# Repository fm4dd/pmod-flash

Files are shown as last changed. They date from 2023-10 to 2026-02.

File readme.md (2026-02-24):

## Flash PMOD



### Description

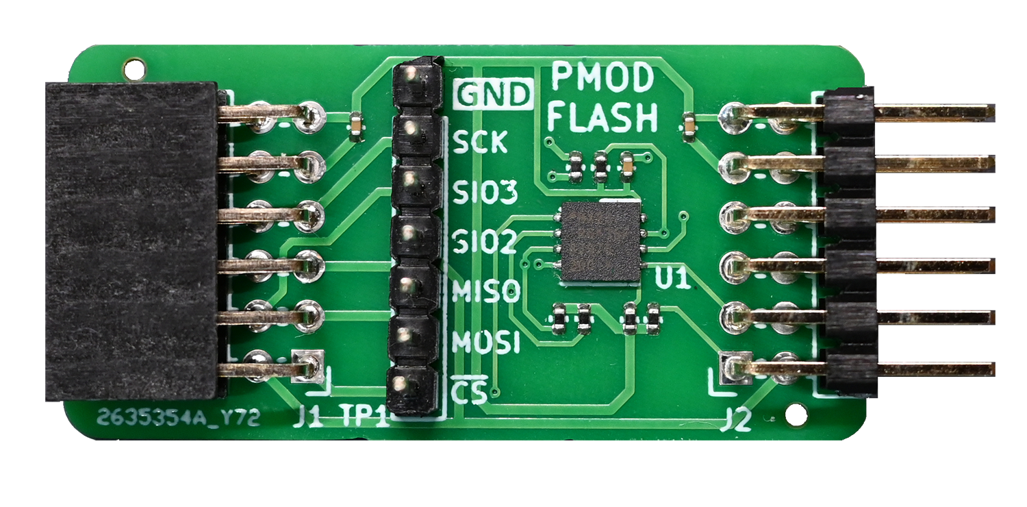
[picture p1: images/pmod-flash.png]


This PMOD provides the Macronix MX25R6435F SPI Flash memory in a pass-through PMOD connector board. The MX25R6435F is a	64Mbit (8MByte) Serial NOR Flash that can operate in multiple modes up to 80Mhz Quad SPI. The PMOD includes the option to install a 7-pin 2.54mm pitch testpoint header for signal and protocol analysis.

https://www.mxic.com.tw/en-us/products/NOR-Flash/Pages/Ultra-Low-Power-Flash.aspx

http://fpga.fm4dd.com/

### Schematic
PMOD Flash Schematics

### PCB Gerber
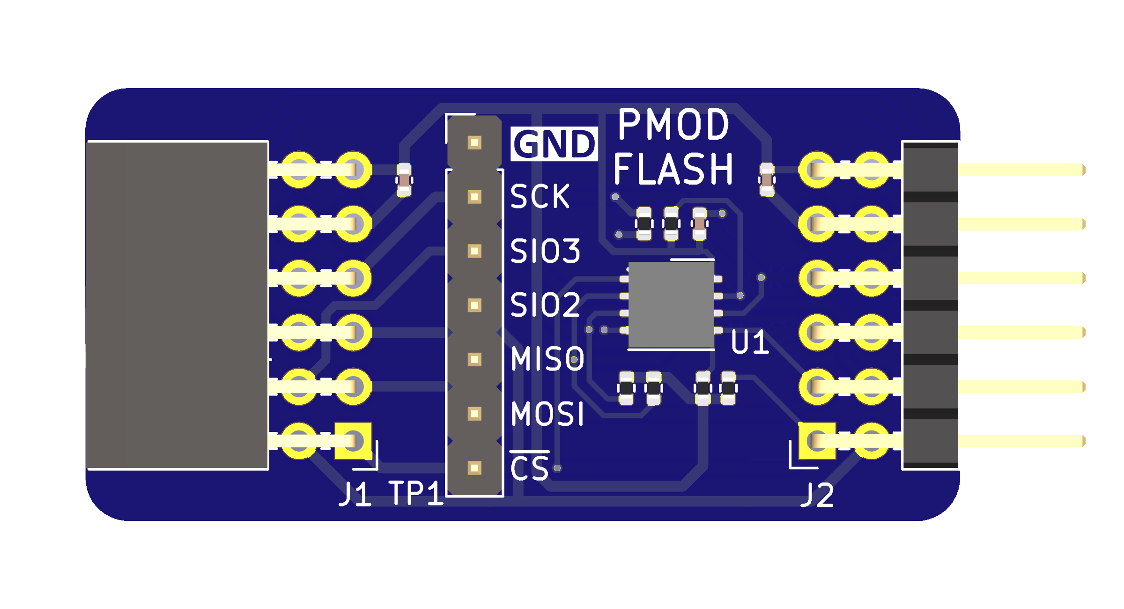
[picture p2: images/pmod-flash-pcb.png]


[PMOD Flash Gerber V1.0](fabfiles/v10/20230921-pmod-flash-gerber.zip)

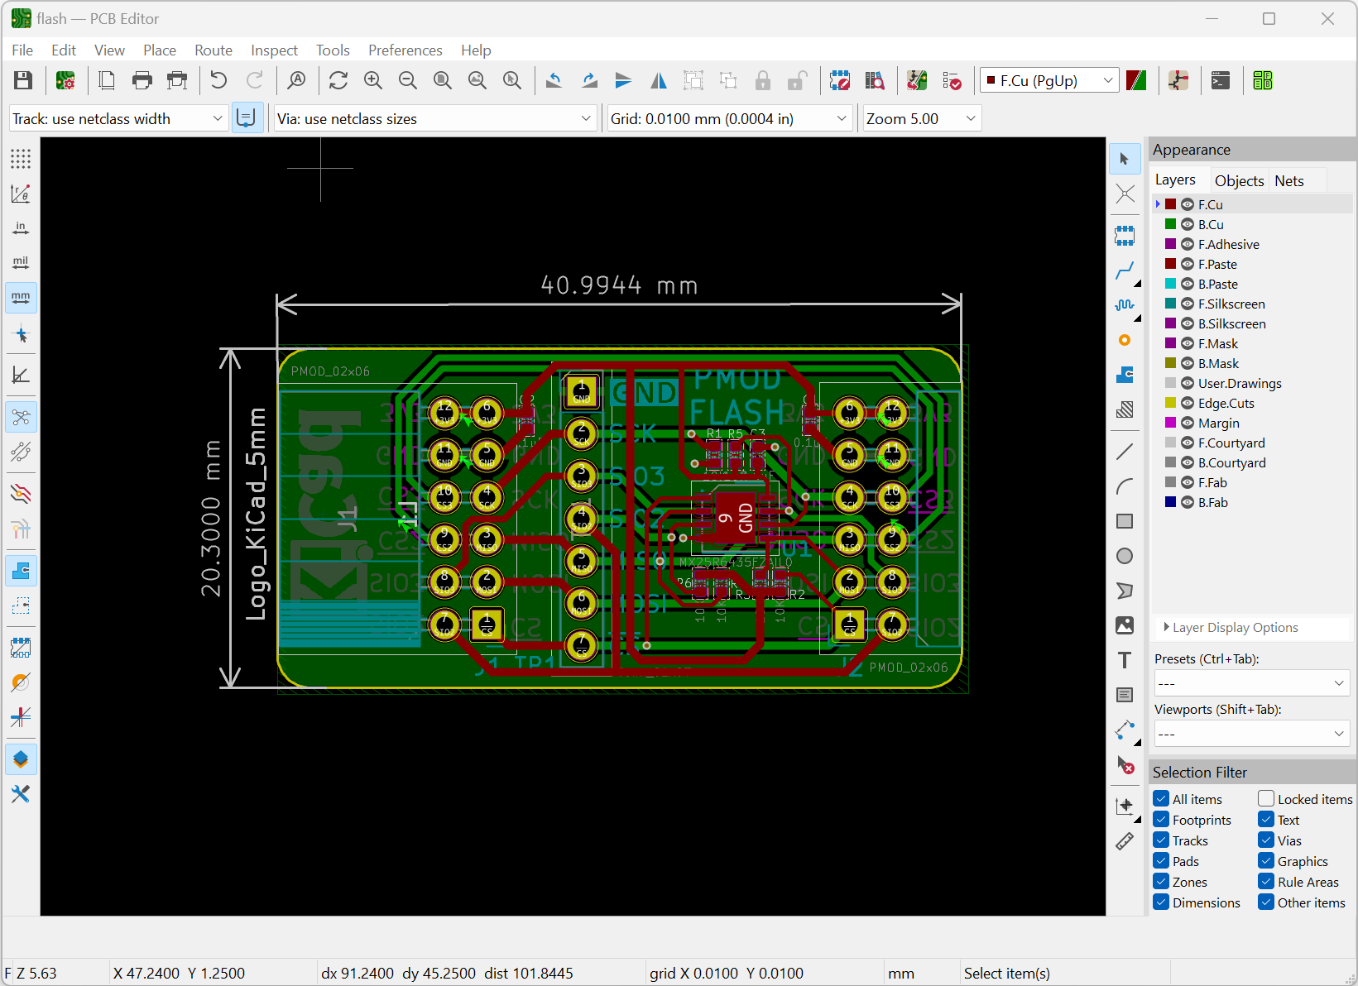
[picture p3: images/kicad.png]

The PMOD Flash module was designed with KiCad 7

### Pin Assignments
<table>
  <tr><th>Pinout</th><th>Pin</th><th>Function</th><th>Pin</th><th>Function</th></tr>
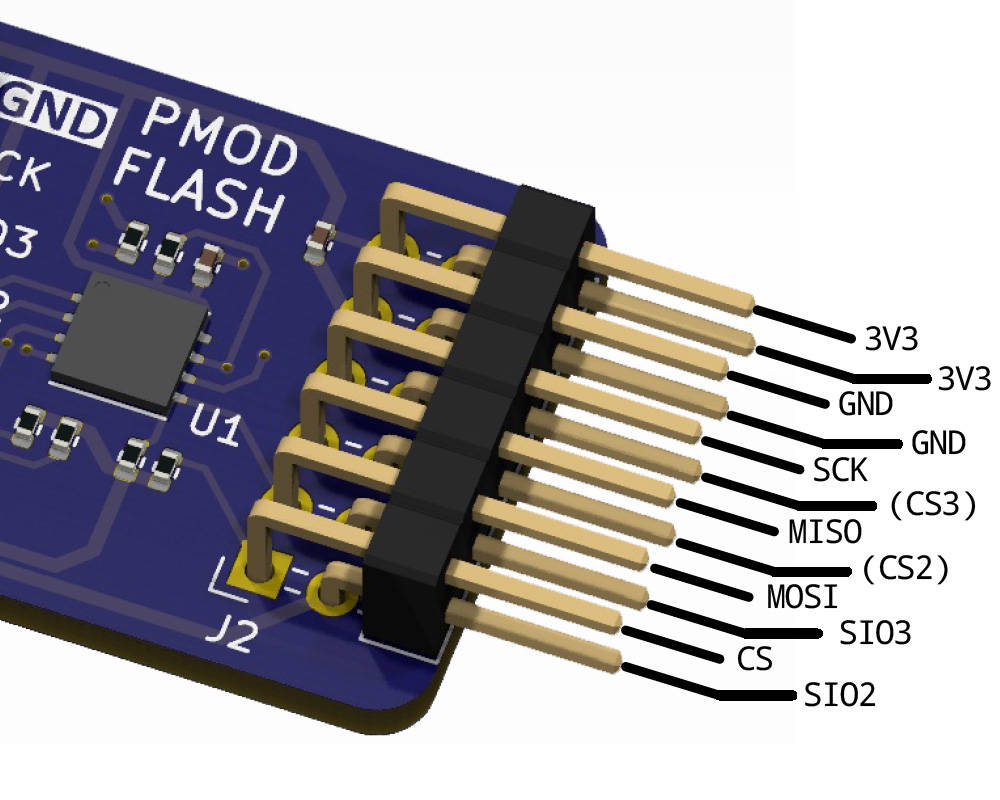
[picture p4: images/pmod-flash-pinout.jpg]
  <tr><td rowspan="6"></td>
        <td>1</td><td>CS</td><td>7</td><td>SIO2</td></tr>
    <tr><td>2</td><td>MOSI</td><td>8</td><td>SIO3</td></tr>
    <tr><td>3</td><td>MISO</td><td>9</td><td> not connected (CS2)</td></tr>
    <tr><td>4</td><td>SCK</td><td>10</td><td>not connected (CS3)</td></tr>
    <tr><td>5</td><td>GND</td><td>11</td><td>GND</td></tr>
    <tr><td>6</td><td>3V3</td><td>12</td><td>3V3</td></tr>
</table>

### Example Code

The following code examples demonstrate the PMOD function for quick verification on various Microcontroller and FPGA platforms.

| Platform | Test Program location | Description |
|---|---|---|
| Arduino |[examples/arduino](examples/arduino) | Flash test adopted from the SparkFun_SPI_SerialFlash library |
| Raspberry  |[examples/rpi](examples/rpi) | Linux has the flashrom program for basic read/write commands |
| Gatemate |[examples/gatemate](examples/gatemate) | Gatemate FPGA test program for basic Flash access validation |
| iCEBreaker |[examples/icebreaker](examples/icebreaker)| iCEBreaker FPGA test program for basic Flash access validation |

### PMOD-Flash Function Tests

PMOD Flash module connected to the PMOD2RPi board, driven by Seeeduino XIAO SAMD21 MCU:

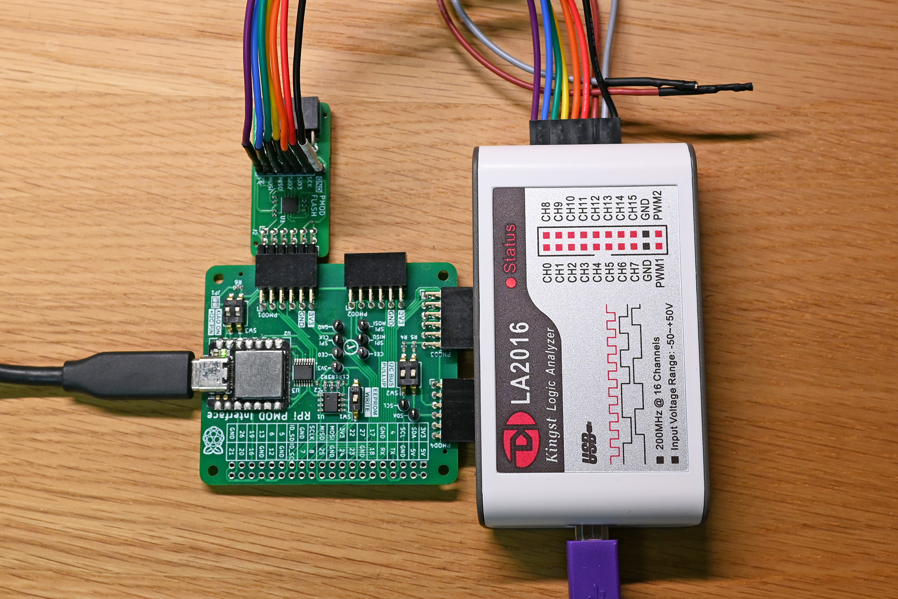
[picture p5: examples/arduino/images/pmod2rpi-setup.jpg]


PMOD Flash module connected to the PMOD2RPi board, interfacing with the Raspberry Pi 4:

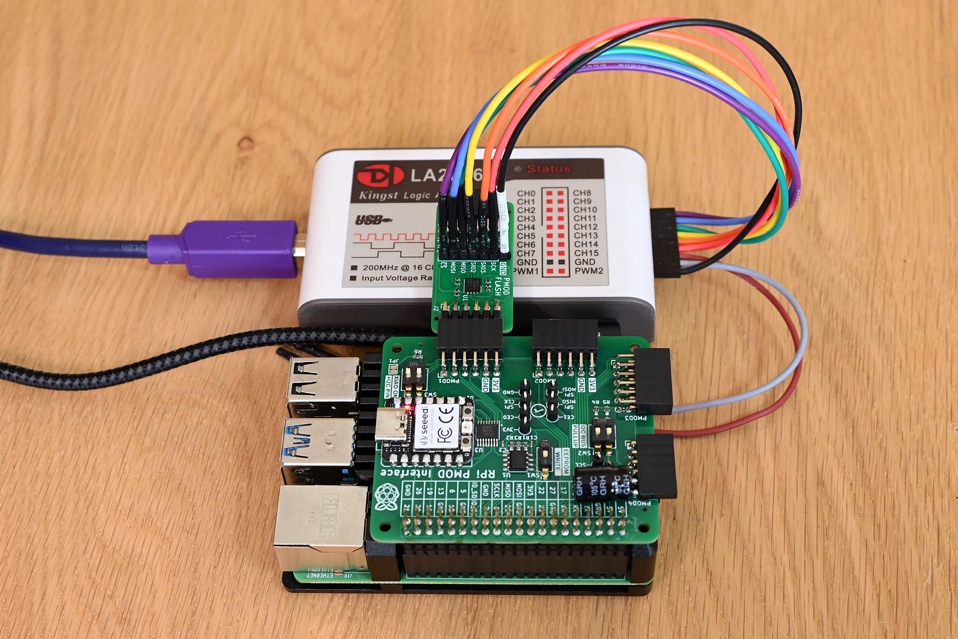
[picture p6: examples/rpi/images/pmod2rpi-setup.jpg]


PMOD Flash module verified running at 50MHz SPI clock speed with the Raspberry Pi 4:

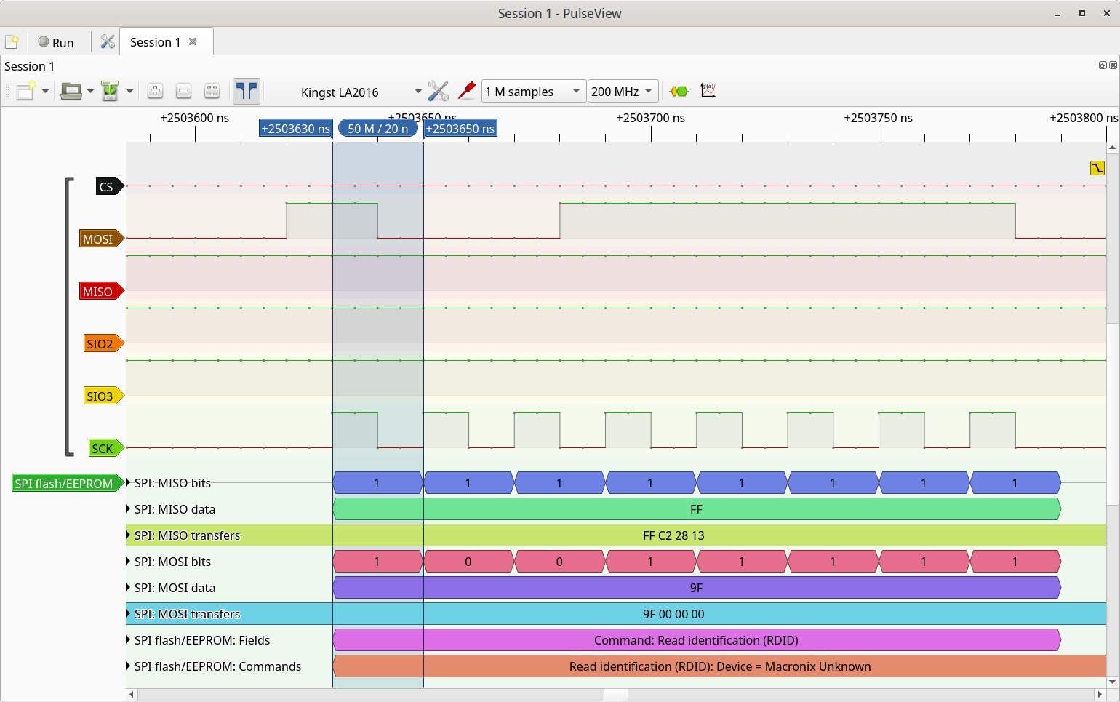
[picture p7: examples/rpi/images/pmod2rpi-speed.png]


PMOD Flash module test on Cologne Chip Gatemate FPGA:

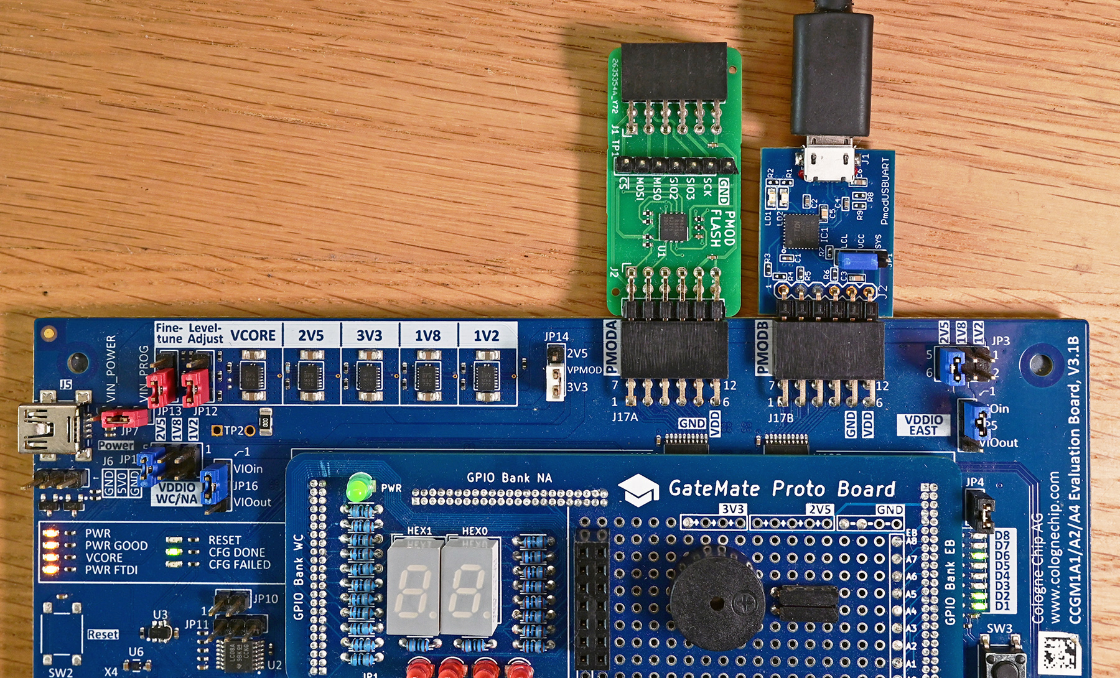
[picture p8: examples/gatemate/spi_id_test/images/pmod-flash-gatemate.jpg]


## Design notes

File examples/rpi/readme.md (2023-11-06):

## Flash PMOD - Raspberry Pi Test Code

### Setup



The PMOD-Flash module has been successfully tested on a Raspberry Pi 4 running Raspberry OS version 11. There, the PMOD-FLash module was connected through the [pmod2rpi board](https://github.com/fm4dd/pmod2rpi). The pmod2rpi board is interfacing with the Raspberry Pi's SPI bus that is exposed on the GPIO pinheader per below connection schematic:

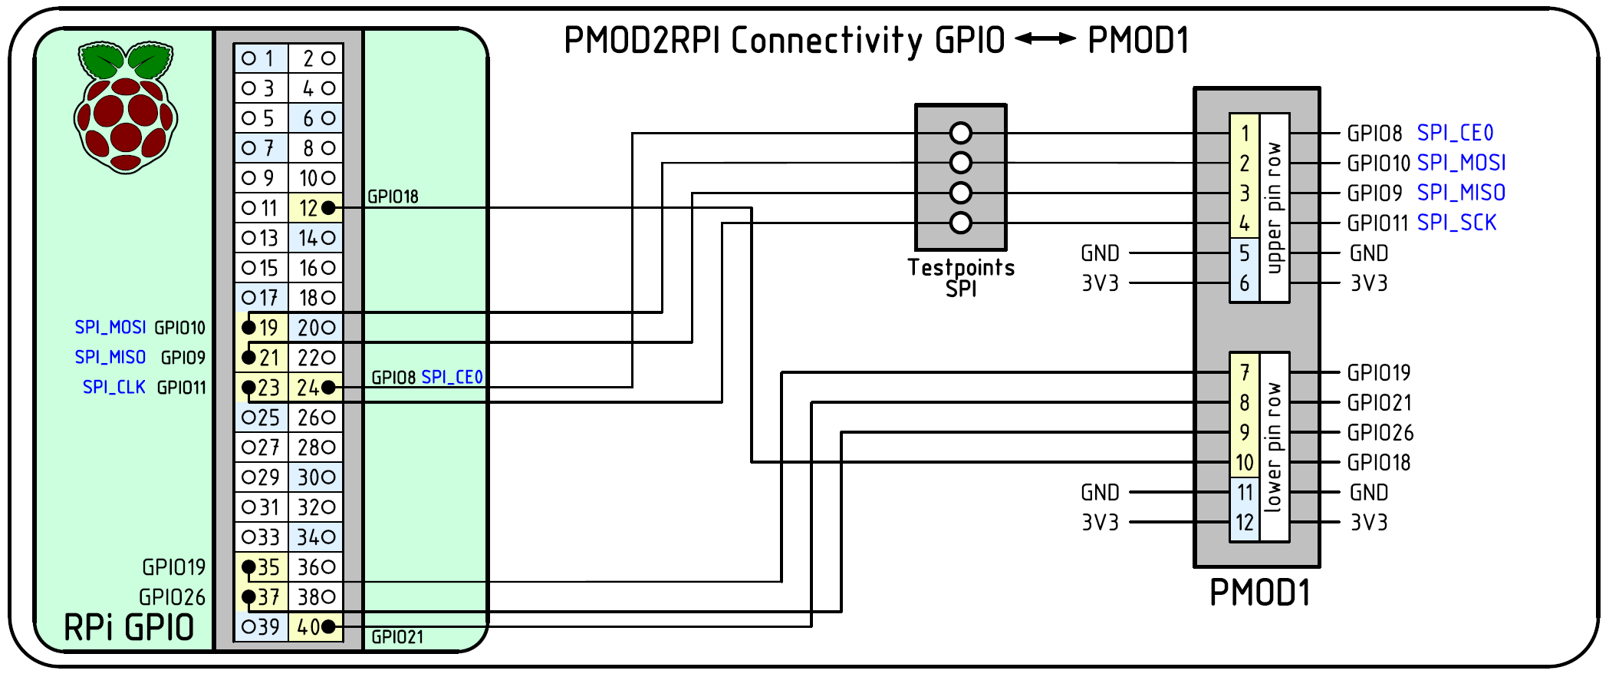
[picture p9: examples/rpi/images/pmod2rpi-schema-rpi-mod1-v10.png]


### Function Test

The Raspberry Pi OS comes with the *flashrom* program that can be used to read or write to the flash module. Below, the *flashrom* program identifies the flash chip vendor and model.

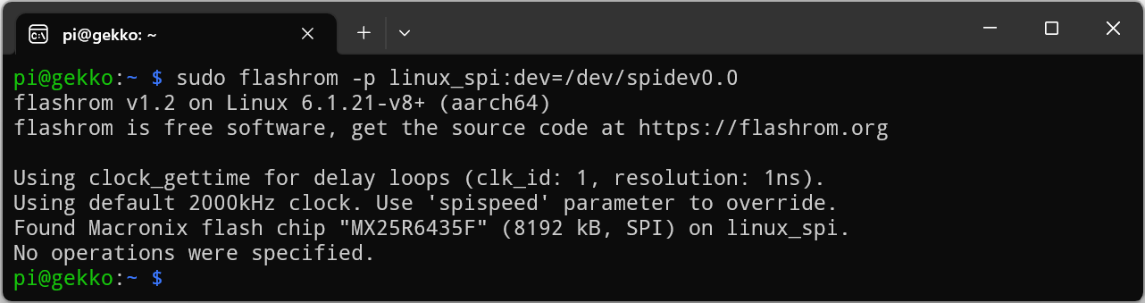
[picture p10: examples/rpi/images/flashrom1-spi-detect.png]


We can dump the entire content from the flash into a local file *rom.img*. The completion time strongly relates to the SPI bus speed setting (given in KHz). In the example below we set 22 MHz for the SPI bus.

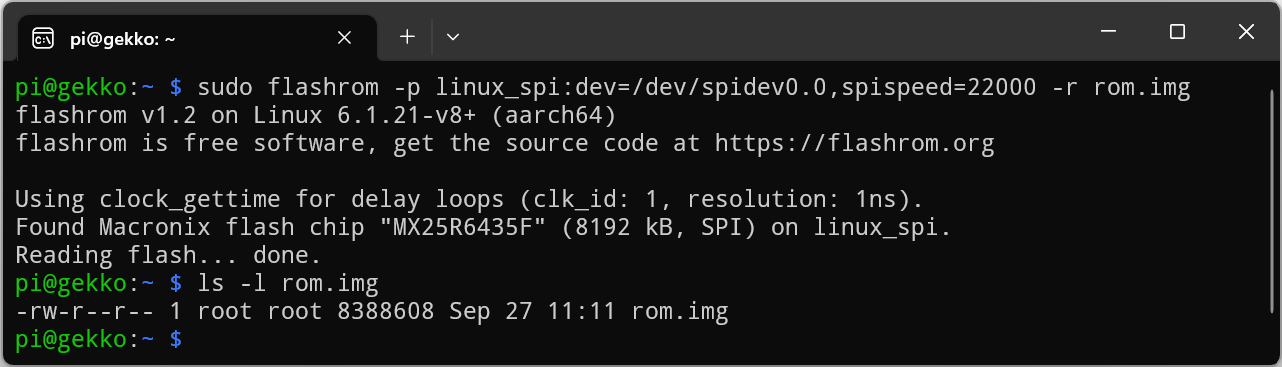
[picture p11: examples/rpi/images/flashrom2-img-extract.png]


After the flash read completes, we can view the flash content from file.

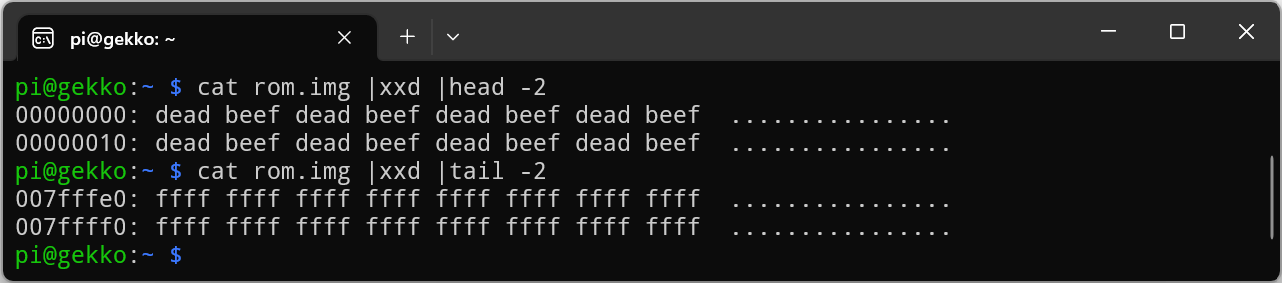
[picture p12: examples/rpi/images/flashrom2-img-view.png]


### SPI Bus Monitoring

 A protocol analyzer was connected directly to the PMOD-Flash analzyer pins to check on SPI clock and protocol information. If a [PMOD-Analyzer board](https://github.com/fm4dd/pmod-analyzer) gets used in between PMOD-flash and pmod2rpi board, the onboard analyzer LEDs must be turned off to let the 10K SPI bus pull-up resistors pull.

Below shows the flash *read identification* command RDID, executed with 50MHz (20 nanoseconds clock period). This is reaching the limit for the attached protocol analyzer, which has a maximum sample rate of 200 MHz. The waveform dots representing the samples show we are down to only two samples for each logic level of the SPI clock *SCK*.



On a Raspberry Pi, the SPI clock is reported to run up to 125MHz max (when running at full core clock speed of 250 MHz).

### Flashrom commands reference

#### Write image to flash

Create a dummy 8M ROM image to write to the flash:
```
pi@gekko:~ $ dd if=/dev/urandom of=flash_8M.img bs=8388608 count=1 conv=notrunc,fsync
1+0 records in
1+0 records out
8388608 bytes (8.4 MB, 8.0 MiB) copied, 0.349986 s, 24.0 MB/s
```

Instead of ```if=/dev/urandom``` we could use ```if=/dev/zero``` to create a image with 0x00.

Write the random data image to flash:

```
pi@gekko:~ $ sudo flashrom -p linux_spi:dev=/dev/spidev0.0,spispeed=22000 -w flash_8M.img
flashrom v1.2 on Linux 6.1.21-v8+ (aarch64)
flashrom is free software, get the source code at https://flashrom.org

Using clock_gettime for delay loops (clk_id: 1, resolution: 1ns).
Found Macronix flash chip "MX25R6435F" (8192 kB, SPI) on linux_spi.
Reading old flash chip contents... done.
Erasing and writing flash chip... Erase/write done.
Verifying flash... VERIFIED.
```

## Erase the flash

When the flash is erased, it flips every bit to 1 (0xFF content):

```
pi@gekko:~ $ sudo flashrom -p linux_spi:dev=/dev/spidev0.0,spispeed=22000 -E
flashrom v1.2 on Linux 6.1.21-v8+ (aarch64)
flashrom is free software, get the source code at https://flashrom.org

Using clock_gettime for delay loops (clk_id: 1, resolution: 1ns).
Found Macronix flash chip "MX25R6435F" (8192 kB, SPI) on linux_spi.
Erasing and writing flash chip... Erase/write done.
```

## Operations on specific Flash Memory Locations

In order to read or write only partial data to flash, we can select the flash region. The *flashrom* program can read the specific memory location from a layout file. The layout file contains lines for "startaddr:endaddr imagename". The *flashrom* manual has more information.

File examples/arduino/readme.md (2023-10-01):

## Flash PMOD - Arduino Test Code

### Setup



The PMOD-Flash module has been successfully tested on a Arduino-class Seeeduino XIAO board. The XIAO uses a Cortex-M0+ SAMD21G18 microcontroller. The original Sparkfun example code has been adopted from the SparkFun_SPI_SerialFlash library with minor changes to enable serial communication and to externalize the SPI clock speed parameter. All credits for the example code go to Sparkfun.

The XIAO is embedded on the [pmod2rpi board](https://github.com/fm4dd/pmod2rpi), and PMOD-Flash was connected to the PMOD1 connector. On the pmod2rpi board, SW3 was in "on" position. This switch toggles the PMOD1 type between I2C and SPI modes, according to Digilents PMOD specification. I used the SPI_Flash_Example.ino sketch example from the Sparkfun library "SparkFun_SPI_SerialFlash". When connecting to the boards PMOD1 connector, the CS signal is connected to XIAO pin-7. For the PMOD2 connector, its XIAO pin-6.

The original sketch misses the serial wait required for the USB connected serial ports. We can add ```while (!Serial) { ; // wait for serial port to connect. Needed for native USB port only}``` right after ```Serial.begin(115200);```

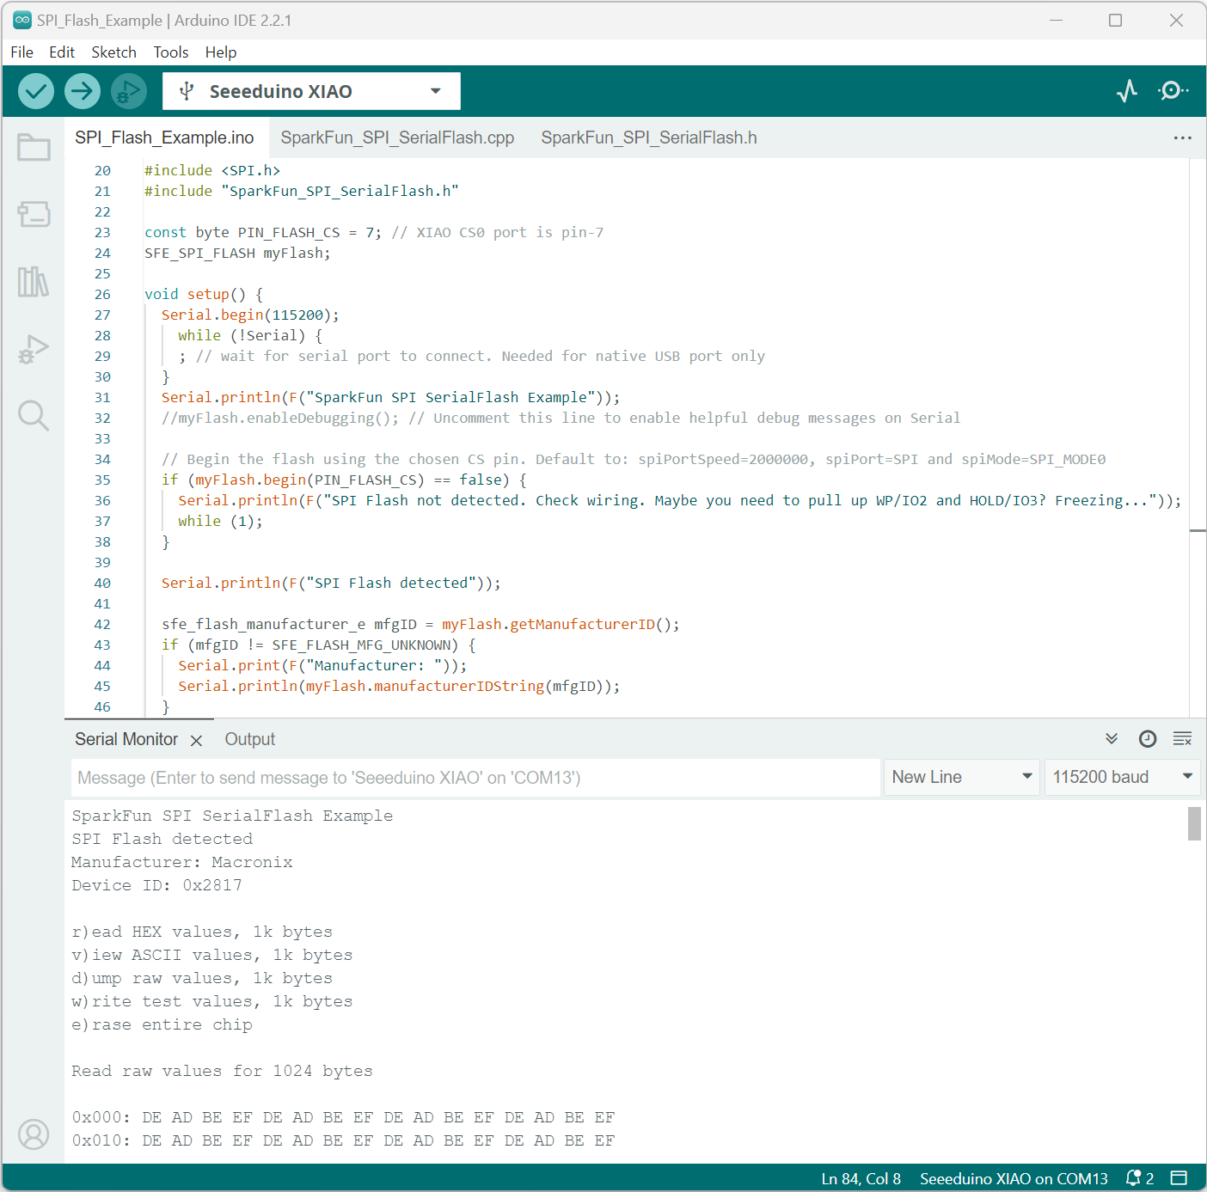
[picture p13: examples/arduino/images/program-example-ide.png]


The example program [SPI_Flash_Example](SPI_Flash_Example/) identifies the flash chip vendor and model, can read from the flash, and write the test byte pattern "de ad be ef" into the first 1K memory of the flash.

### SPI Bus Monitoring

 A protocol analyzer was connected directly to the PMOD-Flash analzyer pins to check on SPI clock and protocol information. If a [PMOD-Analyzer board](https://github.com/fm4dd/pmod-analyzer) gets used in between PMOD-flash and pmod2rpi board, the onboard analyzer LEDs must be turned off to let the 10K SPI bus pull-up resistors pull.

Below shows the flash data write to address 0x0, writing the test pattern "de ad be ef".
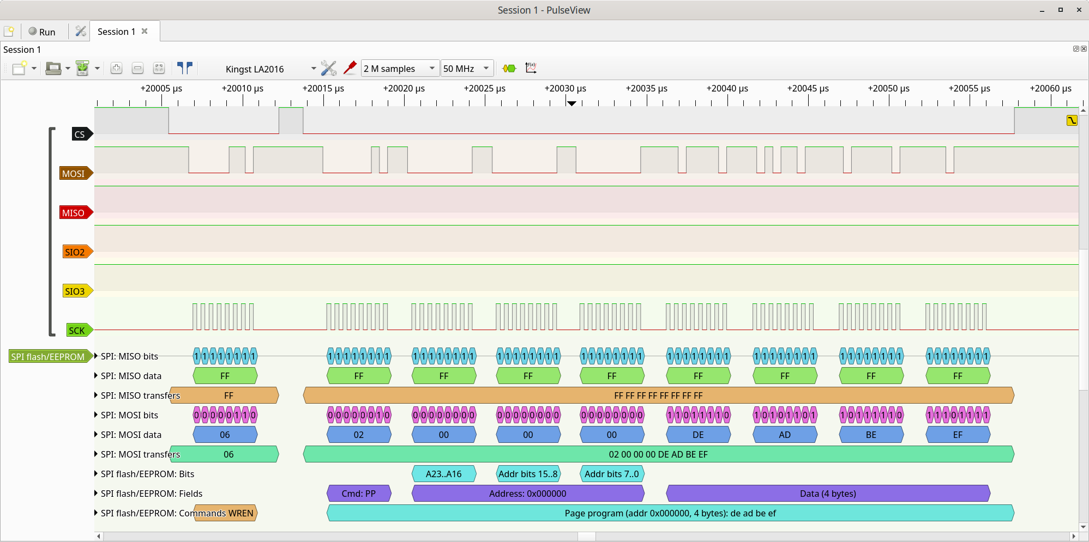
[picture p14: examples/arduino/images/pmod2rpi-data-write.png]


Below shows the flash data read command for address 0x00.
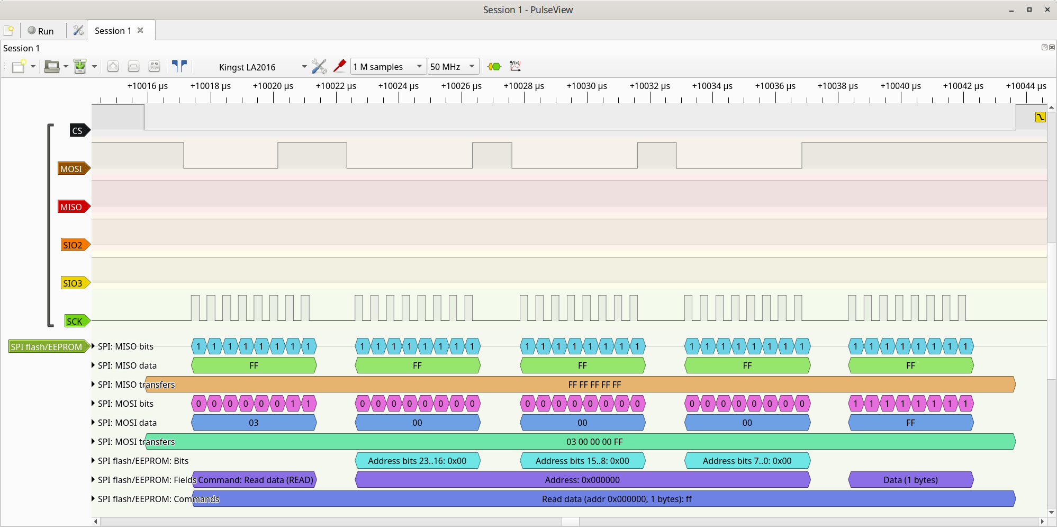
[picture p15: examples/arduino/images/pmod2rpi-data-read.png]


Note the programs default SPI speed is 2 MHz. The max possible SPI master speed of the Cortex-M0 microcontroller SAMD21G18 is 12 MHz. (https://microchip.my.site.com/s/article/SPI-max-clock-frequency-in-SAMD-SAMR-devices)

### Example Program Serial Output
```
SparkFun SPI SerialFlash Example
SPI Flash detected
Manufacturer: Macronix
Device ID: 0x2817

r)ead HEX values, 1k bytes
v)iew ASCII values, 1k bytes
d)ump raw values, 1k bytes
w)rite test values, 1k bytes
e)rase entire chip
```
Typing 'e':
```
Read raw values for 1024 bytes

0x000: FF FF FF FF FF FF FF FF FF FF FF FF FF FF FF FF
0x010: FF FF FF FF FF FF FF FF FF FF FF FF FF FF FF FF
0x020: FF FF FF FF FF FF FF FF FF FF FF FF FF FF FF FF
0x030: FF FF FF FF FF FF FF FF FF FF FF FF FF FF FF FF
0x040: FF FF FF FF FF FF FF FF FF FF FF FF FF FF FF FF
0x050: FF FF FF FF FF FF FF FF FF FF FF FF FF FF FF FF
0x060: FF FF FF FF FF FF FF FF FF FF FF FF FF FF FF FF
...
0x3C0: FF FF FF FF FF FF FF FF FF FF FF FF FF FF FF FF
0x3D0: FF FF FF FF FF FF FF FF FF FF FF FF FF FF FF FF
0x3E0: FF FF FF FF FF FF FF FF FF FF FF FF FF FF FF FF
0x3F0: FF FF FF FF FF FF FF FF FF FF FF FF FF FF FF FF

r)ead HEX values, 1k bytes
v)iew ASCII values, 1k bytes
d)ump raw values, 1k bytes
w)rite test values, 1k bytes
e)rase entire chip
```
Typing 'v':
```
(returns empty lines, 0xFF does not translate into an ASCII character)

r)ead HEX values, 1k bytes
v)iew ASCII values, 1k bytes
d)ump raw values, 1k bytes
w)rite test values, 1k bytes
e)rase entire chip
```
Typing 'd':
 ```        ...
r)ead HEX values, 1k bytes
v)iew ASCII values, 1k bytes
d)ump raw values, 1k bytes
w)rite test values, 1k bytes
e)rase entire chip
```
Typing 'w':
```
Writing test HEX values to first 1024 bytes

r)ead HEX values, 1k bytes
v)iew ASCII values, 1k bytes
d)ump raw values, 1k bytes
w)rite test values, 1k bytes
e)rase entire chip

Typing 'r':

Read raw values for 1024 bytes

0x000: DE AD BE EF DE AD BE EF DE AD BE EF DE AD BE EF
0x010: DE AD BE EF DE AD BE EF DE AD BE EF DE AD BE EF
0x020: DE AD BE EF DE AD BE EF DE AD BE EF DE AD BE EF
0x030: DE AD BE EF DE AD BE EF DE AD BE EF DE AD BE EF
...
0x3C0: DE AD BE EF DE AD BE EF DE AD BE EF DE AD BE EF
0x3D0: DE AD BE EF DE AD BE EF DE AD BE EF DE AD BE EF
0x3E0: DE AD BE EF DE AD BE EF DE AD BE EF DE AD BE EF
0x3F0: DE AD BE EF DE AD BE EF DE AD BE EF DE AD BE EF

r)ead HEX values, 1k bytes
v)iew ASCII values, 1k bytes
d)ump raw values, 1k bytes
w)rite test values, 1k bytes
e)rase entire chip
```
Typing 'e':
```
Erasing entire chip

r)ead HEX values, 1k bytes
v)iew ASCII values, 1k bytes
d)ump raw values, 1k bytes
w)rite test values, 1k bytes
e)rase entire chip
```
Typing 'r':
```
Read raw values for 1024 bytes

0x000: FF FF FF FF FF FF FF FF FF FF FF FF FF FF FF FF
0x010: FF FF FF FF FF FF FF FF FF FF FF FF FF FF FF FF
0x020: FF FF FF FF FF FF FF FF FF FF FF FF FF FF FF FF
0x030: FF FF FF FF FF FF FF FF FF FF FF FF FF FF FF FF
...
0x3C0: FF FF FF FF FF FF FF FF FF FF FF FF FF FF FF FF
0x3D0: FF FF FF FF FF FF FF FF FF FF FF FF FF FF FF FF
0x3E0: FF FF FF FF FF FF FF FF FF FF FF FF FF FF FF FF
0x3F0: FF FF FF FF FF FF FF FF FF FF FF FF FF FF FF FF
```

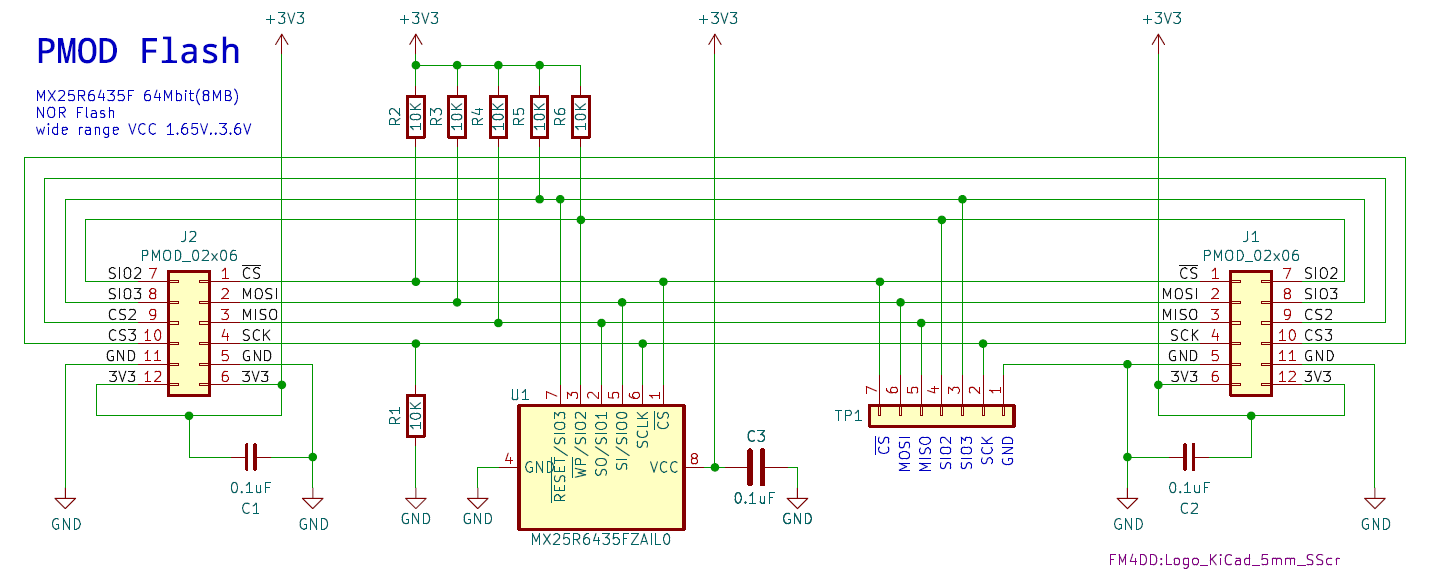
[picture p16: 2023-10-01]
images/schema.png

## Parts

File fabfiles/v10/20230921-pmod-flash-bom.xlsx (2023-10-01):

Comment | Designator | Footprint | JLCPCB Part #（optional）
10K | R1,R2,R3,R4,R5,R6 | R_0402_1005Metric | C25744
0.1uF | C2,C1,C3 | C_0402_1005Metric | C1525
MX25R6435FZAIL0 | U1 | USON-8_4x4mm | C2802847

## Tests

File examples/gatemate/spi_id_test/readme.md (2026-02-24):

## PMOD-FLASH test program

### Description

This is a Verilog test program for the flash chip on PMOD Flash.
It only sends one command 9Fh (Read Identification - RDID), and returns the output to a serial console.

For my test, I connected PMOD Flash to PMODA on the Gatemate E1 FPGA board.
On PMOD2 I have the Digilent pmod USBUART connected to the lower pinrow.

The SPI clock is a simple 4:1 divider, creating a SPI flash clock frequency of 2.5 MHz (10Mhz/4).

Gatemate constraints:
```
## #######################################################
## PMOD-A constraints for github.com/fm4dd/pmod-flash 
## MX25R6435F is a 64Mbit (8MByte) Serial NOR Flash 
## #######################################################
Pin_out "SPIFLASH_CLK"   Loc = "IO_NB_A3";
Pin_out "SPIFLASH_CS_N"  Loc = "IO_NB_A0";
Pin_out "SPIFLASH_MOSI"  Loc = "IO_NB_A1"; # DQ0/MOSI
Pin_in  "SPIFLASH_MISO"  Loc = "IO_NB_A2"; # DQ1/MISO
## #######################################################
## PMOD-B connector constraints for Digilent PMOD USBUART.
## This single-row PMOD is connected to lower (Bx) pin row
## #######################################################
## Lower Row connection  assignment
Pin_out "CTS" Loc = "IO_NB_B4"; # RTS
Pin_out "TXD" Loc = "IO_NB_B5"; # RXD
Pin_in  "RXD" Loc = "IO_NB_B6"; # TXD
Pin_out "RTS" Loc = "IO_NB_B7"; # CTS
```

PMOD Flash module test on Cologne Chip Gatemate FPGA:



### Build FPGA Bitstream

```
$ make
/home/fm/oss-cad-suite/bin/yosys -ql log/synth.log -p 'read -sv src/spi_id_test.v src/emmitter_uart.v; synth_gatemate -top spi_id_test -luttree -nomx8 -vlog net/spi_id_test_synth.v; write_json net/spi_id_test_synth.json'
test -e src/gatemate-e1.ccf || exit
/home/fm/oss-cad-suite/bin/nextpnr-himbaechel --device=CCGM1A1 --json net/spi_id_test_synth.json --write net/spi_id_test_impl.v -o out=net/spi_id_test_impl.txt -o ccf=src/gatemate-e1.ccf --router router2 > log/impl.log
Info: Using uarch 'gatemate' for device 'CCGM1A1'
Info: Using timing mode 'WORST'
Info: Using operation mode 'SPEED'
...
Info: Device utilisation:
Info: 	            USR_RSTN:       0/      1     0%
Info: 	            CPE_COMP:       0/  20480     0%
Info: 	         CPE_CPLINES:      10/  20480     0%
Info: 	               IOSEL:      15/    162     9%
Info: 	                GPIO:      15/    162     9%
Info: 	               CLKIN:       1/      1   100%
Info: 	              GLBOUT:       1/      1   100%
Info: 	                 PLL:       0/      4     0%
Info: 	            CFG_CTRL:       0/      1     0%
Info: 	              SERDES:       0/      1     0%
Info: 	              CPE_LT:     364/  40960     0%
Info: 	              CPE_FF:     100/  40960     0%
Info: 	           CPE_RAMIO:      10/  40960     0%
Info: 	            RAM_HALF:       0/     64     0%
...
Info: Program finished normally.
/home/fm/oss-cad-suite/bin/gmpack --input net/spi_id_test_impl.txt --bit spi_id_test.bit
```

### Board Programming
```
$ make prog
Programming E1 SPI Config:
/home/fm/oss-cad-suite/bin/openFPGALoader  -b gatemate_evb_spi spi_id_test.bit
empty
Jtag frequency : requested 6.00MHz    -> real 6.00MHz   
JEDEC ID: 0xc22817
Detected: Macronix MX25R6435F 128 sectors size: 64Mb
00000000 00000000 00000000 00
start addr: 00000000, end_addr: 00010000
Erasing: [==================================================] 100.00%
Done
Writing: [==================================================] 100.00%
Done
Wait for CFG_DONE DONE
```
### Output
With the UART assigned to the E1 boards PMODB connector pins, we can display the serial data in a terminal window.

```
$ ./terminal.sh 
picocom v3.1

port is        : /dev/ttyUSB2
flowcontrol    : none
baudrate is    : 1000000
parity is      : none
databits are   : 8
stopbits are   : 1
escape is      : C-a
local echo is  : no
noinit is      : no
noreset is     : no
hangup is      : no
nolock is      : no
send_cmd is    : sz -vv
receive_cmd is : rz -vv -E
imap is        : 
omap is        : 
emap is        : crcrlf,delbs,
logfile is     : none
initstring     : none
exit_after is  : not set
exit is        : no

Type [C-a] [C-h] to see available commands
Terminal ready
Chip ID: C2 28 17 
Chip ID: C2 28 17 
Chip ID: C2 28 17 

Terminating...
Thanks for using picocom
```
Exit picocom with CTL-A followed by CTL-X.

Notice the device identification ID is "C2 28 17" = Macronix MX25R6435F.

* Manufacturer C2 = Macronix
* memory type: 28 = 3V (3.3V) Serial NOR Flash
* mem density: 17 = 64Mbit (8 Megabytes)

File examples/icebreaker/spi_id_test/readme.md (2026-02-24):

## PMOD-FLASH test program

### Description

This is a Verilog test program for the flash chip on PMOD Flash.
It only sends one command 9Fh (Read Identification - RDID), and returns the output to a serial console.

For my test, I connected PMOD Flash to PMOD1B on the iCEBreaker FPGA board.
On PMOD2 I connected the Digilent pmod 8LD to get the 8-LED diagnostics output.

iCEBreaker constraints:
```
## ##################################################
## iCEBreaker board constraints
## ##################################################
set_io -nowarn CLK        35 # 12 MHz clock
set_io -nowarn RXD         6
set_io -nowarn TXD         9
set_io -nowarn RESET      10

## ##################################################
## PMOD1B constraints for github.com/fm4dd/pmod-flash
# MX25R6435F is a 64Mbit (8MByte) Serial NOR Flash
## ##################################################
set_io -nowarn SPIFLASH_CS_N 43
set_io -nowarn SPIFLASH_MOSI 38
set_io -nowarn SPIFLASH_MISO 34
set_io -nowarn SPIFLASH_CLK  31

## ##################################################
## PMOD2 connector constraints for Digilent PMOD 8LD
## ##################################################
set_io -nowarn LEDS[7]     27
set_io -nowarn LEDS[6]     25
set_io -nowarn LEDS[5]     21
set_io -nowarn LEDS[4]     19
set_io -nowarn LEDS[3]     26
set_io -nowarn LEDS[2]     23
set_io -nowarn LEDS[1]     20
set_io -nowarn LEDS[0]     18
```

PMOD Flash module test on iCEBreaker FPGA:

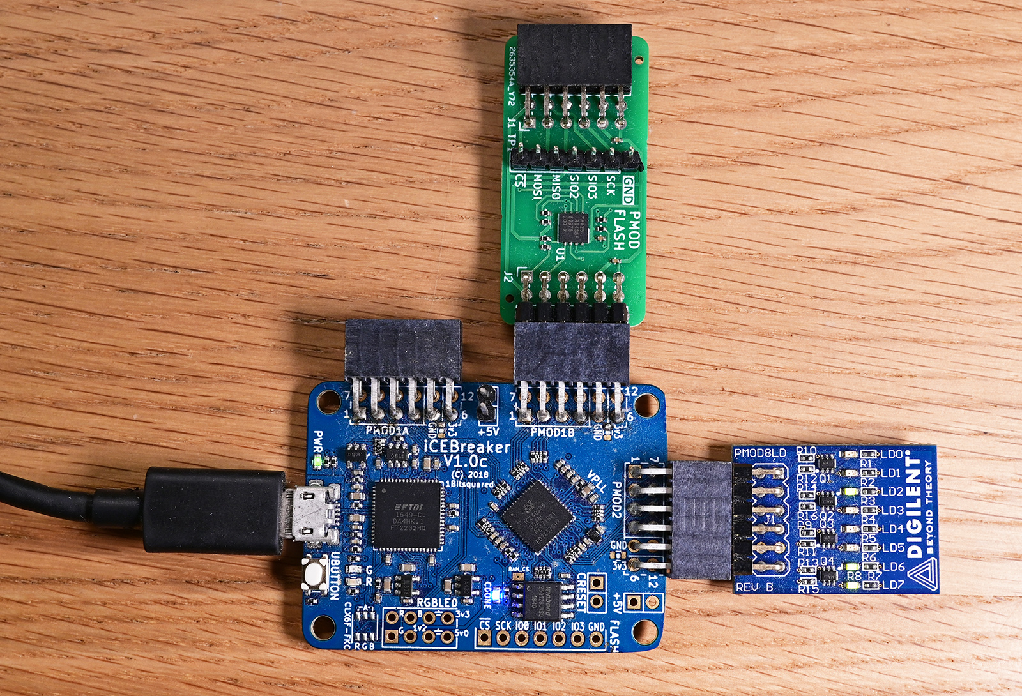
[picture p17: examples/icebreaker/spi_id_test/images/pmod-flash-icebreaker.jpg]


### Build FPGA Bitstream

```
$ make clean; make
rm -f spi_id_test.json spi_id_test.asc spi_id_test.rpt spi_id_test.bin spi_id_test.vcd spi_id_test.tb abc.history spi_id_test.tb
/home/fm/oss-cad-suite/bin/yosys -p 'synth_ice40 -top spi_id_test -json spi_id_test.json' src/spi_id_test.v src/emitter_uart.v

 /----------------------------------------------------------------------------\
 |  yosys -- Yosys Open SYnthesis Suite                                       |
 |  Copyright (C) 2012 - 2026  Claire Xenia Wolf <claire@yosyshq.com>         |
 |  Distributed under an ISC-like license, type "license" to see terms        |
 \----------------------------------------------------------------------------/
 Yosys 0.62+55 (git sha1 29a270c4b, clang++ 18.1.8 -fPIC -O3)
...
=== spi_id_test ===

        +----------Local Count, excluding submodules.
        | 
      231 wires
      438 wire bits
      231 public wires
      438 public wire bits
        8 ports
       15 port bits
        1 cells
        1   $scopeinfo
      328 submodules
       42   SB_CARRY
        1   SB_DFF
       39   SB_DFFE
       21   SB_DFFESR
        8   SB_DFFESS
       26   SB_DFFSR
        5   SB_DFFSS
      186   SB_LUT4
...
Info: Program finished normally.
/home/fm/oss-cad-suite/bin/icetime -d up5k -mtr spi_id_test.rpt spi_id_test.asc
// Reading input .asc file..
// Reading 5k chipdb file..
// Creating timing netlist..
// Timing estimate: 20.52 ns (48.73 MHz)
/home/fm/oss-cad-suite/bin/icepack spi_id_test.asc spi_id_test.bin
```

### Board Programming
```
$ make prog
Programming to Flash:
/home/fm/oss-cad-suite/bin/iceprog spi_id_test.bin
init..
cdone: high
reset..
cdone: low
flash ID: 0xEF 0x40 0x18 0x00
file size: 104090
erase 64kB sector at 0x000000..
erase 64kB sector at 0x010000..
programming..
done.                 
reading..
VERIFY OK             
cdone: high
Bye.
```
### Output
On iCEBreaker we get to onboard UART typically as device /dev/ttyUSB1, we can display the serial data in a terminal window.

```
$ ./terminal.sh 
picocom v3.1

port is        : /dev/ttyUSB1
flowcontrol    : none
baudrate is    : 1000000
parity is      : none
databits are   : 8
stopbits are   : 1
escape is      : C-a
local echo is  : no
noinit is      : no
noreset is     : no
hangup is      : no
nolock is      : no
send_cmd is    : sz -vv
receive_cmd is : rz -vv -E
imap is        : 
omap is        : 
emap is        : crcrlf,delbs,
logfile is     : none
initstring     : none
exit_after is  : not set
exit is        : no

Type [C-a] [C-h] to see available commands
Terminal ready
Chip ID: C2 28 17 
Chip ID: C2 28 17 
Chip ID: C2 28 17 

Terminating...
Thanks for using picocom
```
Exit picocom with CTL-A followed by CTL-X.

Notice the device identification ID is "C2 28 17" = Macronix MX25R6435F.

* Manufacturer C2 = Macronix
* memory type: 28 = 3V (3.3V) Serial NOR Flash
* mem density: 17 = 64Mbit (8 Megabytes)

If the module constraints are wrong and the SPI communication fails, the typical serial output becomes "FF FF FF".

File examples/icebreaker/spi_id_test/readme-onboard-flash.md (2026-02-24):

## OnBoard Flash test program

### Description

This is a Verilog test program for the flash chip on PMOD Flash.
It only sends one command 9Fh (Read Identification - RDID), and returns the output to a serial console.

This code also works with the onboard Flash of the iCEBreaker board.

However by default, the onboard flash enters a Deep Power Down (DPD) mode after the bistream has been loaded.
When the Flash is in DPD, it ignores all standard commands—including RDID (0x9F).
Since it ignores the command, it never drives the MISO line, leaving it pulled high (reading as FF).

This means we either must wake the flash up from Deep Power Down (option A),
or (B) have the programming tell the board to disable Deep Power Down after loading the bitstream.

Option A is to add the DPD wake-up logic into the Verilog code before sending the RDID command.

For (B), we can tell bitstream generator program `icepack` to disable DPD mode.
This is done with the option `icepack -s`: disable final deep-sleep SPI flash command after bitstream is loaded

By adding `-s` into the Makefile, and we can query the onboard flash without additional coding.
In the Makefile, we can simply switch between onboard flash and pmod-flash by enabling the right constraints file.

iCEBreaker constraints for the onboard FLash:
```
## ##################################################
## iCEBreaker board constraints
## ##################################################
set_io -nowarn CLK        35 # 12 MHz clock
set_io -nowarn RXD         6
set_io -nowarn TXD         9
set_io -nowarn RESET      10

## ##################################################
## iCEbreaker onboard SPI Flash
## ##################################################
set_io -nowarn SPIFLASH_CLK  15
set_io -nowarn SPIFLASH_CS_N 16
set_io -nowarn SPIFLASH_MOSI 14
set_io -nowarn SPIFLASH_MISO 17

## ##################################################
## PMOD2 connector constraints for Digilent PMOD 8LD
## ##################################################
set_io -nowarn LEDS[7]     27
set_io -nowarn LEDS[6]     25
set_io -nowarn LEDS[5]     21
set_io -nowarn LEDS[4]     19
set_io -nowarn LEDS[3]     26
set_io -nowarn LEDS[2]     23
set_io -nowarn LEDS[1]     20
set_io -nowarn LEDS[0]     18
```

PMOD Flash module test on iCEBreaker FPGA:



### Build FPGA Bitstream

```
$ make clean; make
rm -f spi_id_test.json spi_id_test.asc spi_id_test.rpt spi_id_test.bin spi_id_test.vcd spi_id_test.tb abc.history spi_id_test.tb
/home/fm/oss-cad-suite/bin/yosys -p 'synth_ice40 -top spi_id_test -json spi_id_test.json' src/spi_id_test.v src/emitter_uart.v

 /----------------------------------------------------------------------------\
 |  yosys -- Yosys Open SYnthesis Suite                                       |
 |  Copyright (C) 2012 - 2026  Claire Xenia Wolf <claire@yosyshq.com>         |
 |  Distributed under an ISC-like license, type "license" to see terms        |
 \----------------------------------------------------------------------------/
 Yosys 0.62+55 (git sha1 29a270c4b, clang++ 18.1.8 -fPIC -O3)
...
Info: Device utilisation:
Info: 	         ICESTORM_LC:     210/   5280     3%
Info: 	        ICESTORM_RAM:       0/     30     0%
Info: 	               SB_IO:      15/     96    15%
Info: 	               SB_GB:       3/      8    37%
Info: 	        ICESTORM_PLL:       0/      1     0%
Info: 	         SB_WARMBOOT:       0/      1     0%
Info: 	        ICESTORM_DSP:       0/      8     0%
Info: 	      ICESTORM_HFOSC:       0/      1     0%
Info: 	      ICESTORM_LFOSC:       0/      1     0%
Info: 	              SB_I2C:       0/      2     0%
Info: 	              SB_SPI:       0/      2     0%
Info: 	              IO_I3C:       0/      2     0%
Info: 	         SB_LEDDA_IP:       0/      1     0%
Info: 	         SB_RGBA_DRV:       0/      1     0%
Info: 	      ICESTORM_SPRAM:       0/      4     0%
...
Info: Program finished normally.
/home/fm/oss-cad-suite/bin/icetime -d up5k -mtr spi_id_test.rpt spi_id_test.asc
// Reading input .asc file..
// Reading 5k chipdb file..
// Creating timing netlist..
// Timing estimate: 20.52 ns (48.73 MHz)
/home/fm/oss-cad-suite/bin/icepack -s spi_id_test.asc spi_id_test.bin
```

### Board Programming
```
$ make prog
Programming to Flash:
/home/fm/oss-cad-suite/bin/iceprog spi_id_test.bin
init..
cdone: high
reset..
cdone: low
flash ID: 0xEF 0x40 0x18 0x00
file size: 104090
erase 64kB sector at 0x000000..
erase 64kB sector at 0x010000..
programming..
done.                 
reading..
VERIFY OK             
cdone: high
Bye.
```
### Output
On iCEBreaker we get to onboard UART typically as device /dev/ttyUSB1, we can display the serial data in a terminal window.

```
$ ./terminal.sh 
picocom v3.1

port is        : /dev/ttyUSB1
flowcontrol    : none
baudrate is    : 1000000
parity is      : none
databits are   : 8
stopbits are   : 1
escape is      : C-a
local echo is  : no
noinit is      : no
noreset is     : no
hangup is      : no
nolock is      : no
send_cmd is    : sz -vv
receive_cmd is : rz -vv -E
imap is        : 
omap is        : 
emap is        : crcrlf,delbs,
logfile is     : none
initstring     : none
exit_after is  : not set
exit is        : no

Type [C-a] [C-h] to see available commands
Terminal ready
Chip ID: EF 40 18 
Chip ID: EF 40 18 
Chip ID: EF 40 18 

Terminating...
Thanks for using picocom
```
Exit picocom with CTL-A followed by CTL-X.

Notice the device identification ID is "EF 40 18" = Winbond W25Q128.

* Manufacturer EF = Winbond
* memory type: 40 = W25Q series
* mem density: 18 = 128Mbit (16 Megabytes. Capacity 0x18 = 24 decimal, 2^24 bits = 16MB) 

If the module constraints are wrong and the SPI communication fails, the typical serial output becomes "FF FF FF".

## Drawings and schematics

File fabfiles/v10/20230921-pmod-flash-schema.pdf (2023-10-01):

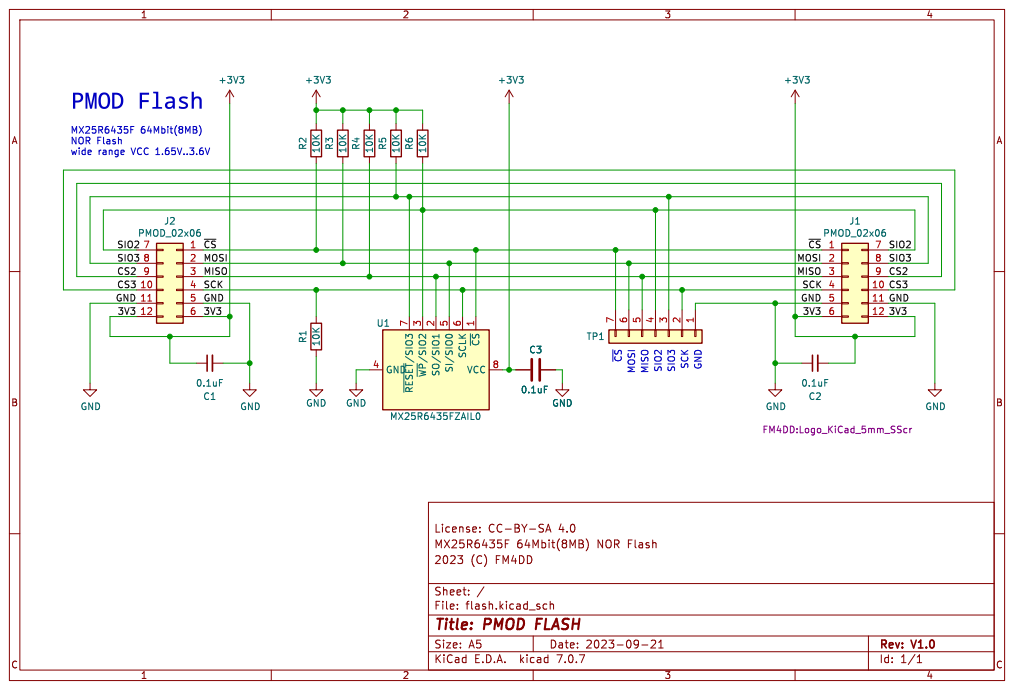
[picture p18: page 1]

Id: 1/1 Title: PMOD FLASH

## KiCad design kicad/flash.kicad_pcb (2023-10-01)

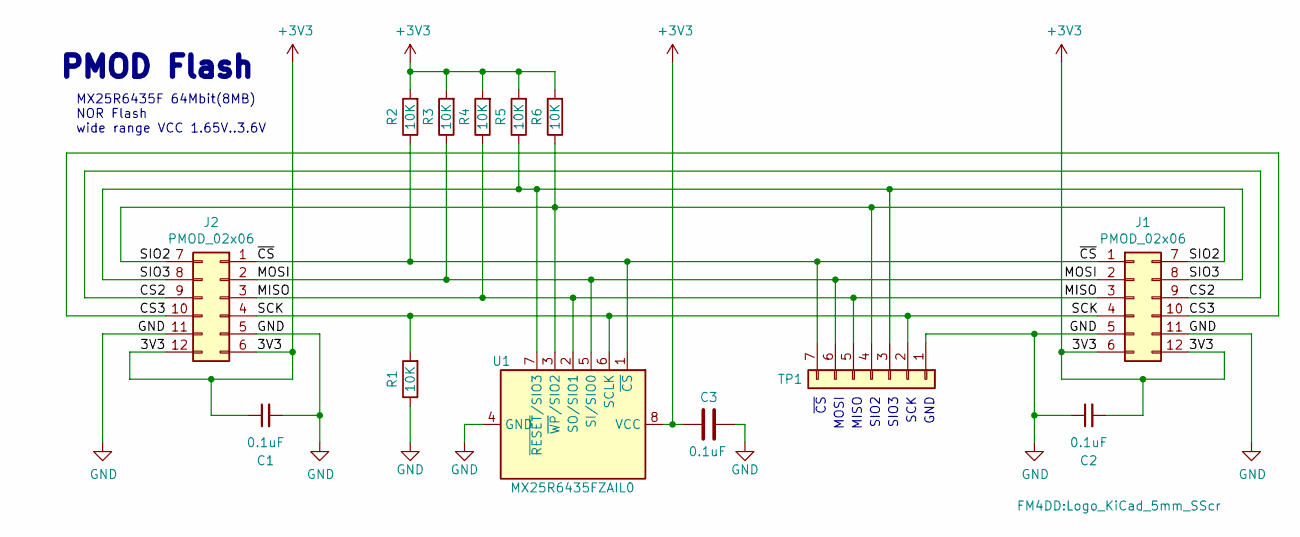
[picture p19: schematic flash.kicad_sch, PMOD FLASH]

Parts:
C1, C2: 0.1uF; C_0402_1005Metric
C3: 0.1uF; C_0402_1005Metric; MPN CC0402KRX7R7BB104; LCSC C327009
J1: PMOD_02x06; PMODPinSocket_2x06_P2.54mm_Horizontal
J2: PMOD_02x06; PMODHeader_2x06_P2.54mm_Horizontal
L1: Logo_KiCad_5mm; Logo_KiCad_5mm_SScr
R1, R2, R3, R4, R5, R6: 10K; R_0402_1005Metric; MPN RC0402JR-075K1L
TP1: Conn_01x07; PinHeader_1x07_P2.54mm_Vertical
U1: MX25R6435FZAIL0; USON-8_4x4mm

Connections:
+3V3: C1.1, C2.2, C3.1, J1.6, J1.12, J2.6, J2.12, R2.2, R3.2, R4.2, R5.2, R6.2, U1.8 (VCC)
/CS2: J1.9, J2.9
/CS3: J1.10, J2.10
/MISO: J1.3, J2.3, R4.1, TP1.5, U1.2 (SO/SIO1)
/MOSI: J1.2, J2.2, R3.1, TP1.6, U1.5 (SI/SIO0)
/SCK: J1.4, J2.4, R1.2, TP1.2, U1.6 (SCLK)
/SIO2: J1.7, J2.7, R6.1, TP1.4, U1.3 (~WP/SIO2)
/SIO3: J1.8, J2.8, R5.1, TP1.3, U1.7 (~RESET/SIO3)
/~CS: J1.1, J2.1, R2.1, TP1.7, U1.1 (~CS)
GND: C1.2, C2.1, C3.2, J1.5, J1.11, J2.5, J2.11, R1.1, TP1.1, U1.4 (GND), U1.9 (GND)

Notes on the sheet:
MX25R6435F 64Mbit(8MB) NOR Flash wide range VCC 1.65V..3.6V
SIO2
SCK
MISO
~{CS}
PMOD Flash
GND
SIO3
MOSI

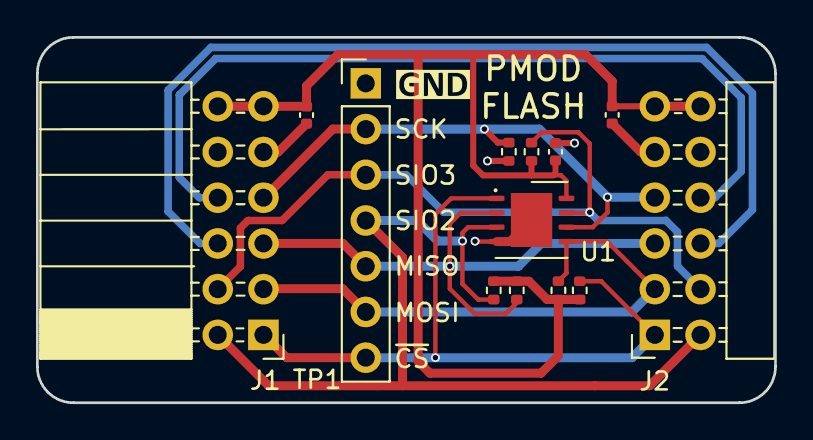
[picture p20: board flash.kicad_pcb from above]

Board: 2 copper layers, 41.0 x 20.3 mm, 14 parts (1 on the bottom side), 10 nets.

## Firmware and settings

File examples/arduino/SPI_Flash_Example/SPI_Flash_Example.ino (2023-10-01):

/*
  Author: Nathan Seidle (with a bit of help from Paul Clark)
  Created: January 29, 2021
  License: Lemonadeware. Buy me a lemonade (or other) someday.

  This sketch demonstrates how to interact with SPI flash such as the:
  128mb W25Q128JV
  4mbit AT25SF041
  16mbit GD25Q16C
  64mbit AT45DB641E
  32mbit IS25WP032D

  If you are using (e.g.) the W25Q128JV - as used on the SparkX Serial Flash Breakout -
  you will need to pull the WP/IO2 and HOLD/IO3 pins high otherwise the chip will not communicate.

  Feel like supporting open source hardware?
  Buy a board from SparkFun!
  https://www.sparkfun.com/products/17115
*/
#include <SPI.h>
#include "SparkFun_SPI_SerialFlash.h"

const byte PIN_FLASH_CS = 7; // XIAO CS0 port is pin-7
const uint32_t SPI_PORT_SPEED = 2000000; // set SPI speed between 1..4MHz (SAMD21 max. 6MHz)
SFE_SPI_FLASH myFlash;

void setup() {
  Serial.begin(115200);
    while (!Serial) {
    ; // wait for serial port to connect. Needed for native USB port only
  }
  Serial.println(F("SparkFun SPI SerialFlash Example"));
  //myFlash.enableDebugging(); // Uncomment this line to enable helpful debug messages on Serial

  // Begin the flash using the chosen CS pin and SPI_PORT_SPEED. Defaults to spiPort=SPI and spiMode=SPI_MODE0
  if (myFlash.begin(PIN_FLASH_CS, SPI_PORT_SPEED) == false) {
    Serial.println(F("SPI Flash not detected. Check wiring. Maybe you need to pull up WP/IO2 and HOLD/IO3? Freezing..."));
    while (1);
  }

  Serial.println(F("SPI Flash detected"));

  sfe_flash_manufacturer_e mfgID = myFlash.getManufacturerID();
  if (mfgID != SFE_FLASH_MFG_UNKNOWN) {
    Serial.print(F("Manufacturer: "));
    Serial.println(myFlash.manufacturerIDString(mfgID));
  }
  else {
    uint8_t unknownID = myFlash.getRawManufacturerID(); // Read the raw manufacturer ID
    Serial.print(F("Unknown manufacturer ID: 0x"));
    if (unknownID < 0x10) Serial.print(F("0")); // Pad the zero
    Serial.println(unknownID, HEX);
  }

  Serial.print(F("Device ID: 0x"));
  Serial.println(myFlash.getDeviceID(), HEX);
}

void loop()
{
  Serial.println();
  Serial.println("r)ead HEX values, 1k bytes");
  Serial.println("v)iew ASCII values, 1k bytes");
  Serial.println("d)ump raw values, 1k bytes");
  Serial.println("w)rite test values, 1k bytes");
  Serial.println("e)rase entire chip");
  Serial.println();

  while (Serial.available()) Serial.read(); //Clear the RX buffer
  while (Serial.available() == 0); //Wait for a character

  byte choice = Serial.read();

  if (choice == 'r') {
    Serial.println("Read raw values for 1024 bytes");

    for (int x = 0 ; x < 0x0400 ; x++) {
      if (x % 16 == 0) {
        Serial.println();
        Serial.print("0x");
        if (x < 0x100) Serial.print("0");
        if (x < 0x10) Serial.print("0");
        Serial.print(x, HEX);
        Serial.print(": ");
      }

      byte val = myFlash.readByte(x);
      if (val < 0x10) Serial.print("0");
      Serial.print(val, HEX);
      Serial.print(" ");
    }

    Serial.println();

    for (int x = 0 ; x < 0x0400 ; x++) {
      if (x % 16 == 0) Serial.println();

      byte val = myFlash.readByte(x);
      if (isAlphaNumeric(val)) Serial.write(val);
    }
  }
  else if (choice == 'd') {
    for (int x = 0 ; x < 0x0400 ; x++) {
      byte val = myFlash.readByte(x);
      Serial.write(val);
    }
  }
  else if (choice == 'e') {
    Serial.println("Erasing entire chip");
    myFlash.erase();
  }
  else if (choice == 'w') {
    Serial.println("Writing test HEX values to first 1024 bytes");
    uint8_t myVal[4] = {0xDE, 0xAD, 0xBE, 0xEF};
    for (int x = 0 ; x < 0x0400 ; x += 4) {
      myFlash.writeBlock(x, myVal, 4); //Address, pointer, size
    }
  }
  else {
    Serial.print("Unknown choice: ");
    Serial.write(choice);
    Serial.println();
  }
}

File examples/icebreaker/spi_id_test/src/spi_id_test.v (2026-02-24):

// -------------------------------------------------------
// MODULE: spi_id_test (SPI Flash Identification Test)
// @20260223 fm4dd
//
// Tested pmod-flash (https://github.com/fm4dd/pmod-flash)
// connected to PMOD1B on the iCEBreaker FPGA board
// and Digilent pmod8LD connected to PMOD2 for LED output
// 
// FUNCTION: 
// This module performs a JEDEC "Read Identification" (RDID) test on an 
// external SPI Flash (specifically tested with Macronix MX25R series).
//
// OPERATION:
// 1. Waits for a Power-On Reset delay (~13ms) to ensure Flash IC is stable.
// 2. On trigger (RESET button), pulls CS_N low and sends command 0x9F.
// 3. Immediately reads 3 bytes (Manufacturer ID, Memory Type, Density).
// 4. Converts these binary bytes into Hexadecimal ASCII characters.
// 5. Sends the hex string (e.g., "C2 28 17") over UART at the defined Baud Rate.
// 6. Terminates the SPI session by pulling CS_N high and enters a DONE state.
// -------------------------------------------------------
`default_nettype none

module spi_id_test #(
    parameter TOTAL_BYTES   = 3,          // Standard JEDEC ID is 3 bytes
    parameter BAUD_RATE     = 1_000_000,  // Target Serial Speed
    parameter CLK_FREQ      = 12_000_000  // 12MHz System Clock
)(
    input  wire        CLK,           // 10MHz hardware clock
    input  wire        RESET,         // Button trigger (active high)
    output wire [7:0]  LEDS,          // Visual status
    output reg         SPIFLASH_CLK,  // SPI SCLK
    output reg         SPIFLASH_CS_N, // SPI Chip Select (Active Low)
    output reg         SPIFLASH_MOSI, // Master Out Slave In
    input  wire        SPIFLASH_MISO, // Master In Slave Out
    output wire        TXD            // UART Transmit
);

    // --- 1. Clock, Reset, and Power-Up Timing ---
    
    // Macronix MX25R chips require a delay (tVSL) after power reaches minimum VCC.
    // At 10MHz, 2^17 cycles is approx 13.1ms, well above the required 800us.
    reg [17:0] pwr_on_cnt = 0;
    wire pwr_ready = pwr_on_cnt[17];
    always @(posedge CLK) if (!pwr_ready) pwr_on_cnt <= pwr_on_cnt + 1;

    // Synchronous internal reset for the state machine
    reg [3:0] rst_cnt = 0;
    wire sys_rst = !rst_cnt[3];
    always @(posedge CLK) if (!rst_cnt[3]) rst_cnt <= rst_cnt + 1;

    // Button Edge Detection Logic
    // Detects the transition from 0 to 1 so the command runs only once per press
    reg [16:0] db_cnt = 0;   // ~6.5ms debounce at 10MHz
    reg        btn_state = 0;
    reg        reset_prev = 0;
    wire       reset_trigger;

    always @(posedge CLK) begin
        // If button matches current state, reset counter
        if (RESET == btn_state) begin
            db_cnt <= 0;
        end else begin
            // If button is different, count up until stable
            db_cnt <= db_cnt + 1;
            if (db_cnt[16]) begin
                btn_state <= RESET;
                db_cnt <= 0;
            end
        end
        // Standard edge detection on the debounced signal
        reset_prev <= btn_state;
    end
    assign reset_trigger = (btn_state == 1'b1 && reset_prev == 1'b0);

    // --- 2. State Machine & String ROM ---
    localparam IDLE       = 0, // Wait for button/power ready
               SEND_STR   = 1, // Sends the "Chip ID: " prefix
               CMD_SEND   = 2, // Shift out 8-bit command (0x9F)
               READ_BYTE  = 3, // Shift in 8-bit response from MISO
               HEX_CONV   = 4, // Convert byte to Hex ASCII characters
               UART_SEND  = 5, // Send ASCII characters over serial
               SEND_NL    = 6, // Sends \r\n at the end over serial
               DONE       = 7; // End SPI transaction (CS_N high)

    reg [2:0] state = IDLE;
    reg [3:0] str_ptr;         // Pointer for indexing the string/newline

    // Helper: String storage for "Chip ID: " (9 chars)
    // Using a function or case inside the state machine is cleaner for small strings
    reg [7:0] prefix_rom [0:8];
    initial begin
        prefix_rom[0]="C"; prefix_rom[1]="h"; prefix_rom[2]="i"; prefix_rom[3]="p"; 
        prefix_rom[4]=" "; prefix_rom[5]="I"; prefix_rom[6]="D"; prefix_rom[7]=":"; 
        prefix_rom[8]=" ";
    end

    // SPI/UART Registers
    reg [7:0] shift_reg, u_data;
    reg [3:0] bit_cnt;
    reg [1:0] byte_cnt, spi_divider, ascii_step;
    reg u_valid;
    wire u_ready;

    // Helper function: Converts 4-bit hex value to 8-bit ASCII character
    function [7:0] to_ascii;
        input [3:0] nibble;
        begin
            to_ascii = (nibble < 10) ? (8'h30 + nibble) : (8'h37 + nibble);
        end
    endfunction

    // --- 3. Main SPI Control Logic ---
    always @(posedge CLK) begin
        if (sys_rst) begin
            state <= IDLE; 
            SPIFLASH_CS_N <= 1; 
            SPIFLASH_CLK <= 0; 
            u_valid <= 0;
            SPIFLASH_MOSI <= 0;
        end else begin
            case (state)
                
                // [IDLE]: Wait for manual trigger and ensure Flash is powered up
                IDLE: begin
                    u_valid <= 0; 
                    SPIFLASH_CS_N <= 1;
                    SPIFLASH_CLK <= 0;
                    // Using reset_trigger (edge)
                    if (reset_trigger && pwr_ready) begin
                        state <= SEND_STR;
                        str_ptr <= 0; // Ensure prefix starts at index 0
                        state <= SEND_STR;
                        SPIFLASH_CS_N <= 0; // Assert Chip Select
                        shift_reg <= 8'h9F; // Load RDID Command
                        bit_cnt <= 0;
                        byte_cnt <= 0;
                        spi_divider <= 0;
                    end
                end

                // [SEND_STR]: Stream the prefix string to serial
                SEND_STR: begin
                    u_data <= prefix_rom[str_ptr];
                    u_valid <= 1;
                    if (u_ready && u_valid) begin
                        u_valid <= 0;
                        if (str_ptr == 8) state <= CMD_SEND;
                        else str_ptr <= str_ptr + 1;
                    end
                end
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

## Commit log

2023-10-01 initial check-in
    [20230921-pmod-flash-bom.xlsx, flash.kicad_pcb, flash.kicad_sch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]
2026-02-23 Add SPI flash example for Gatemate FPGA
    [flash.kicad_sch]

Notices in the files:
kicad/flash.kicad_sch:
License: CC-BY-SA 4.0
